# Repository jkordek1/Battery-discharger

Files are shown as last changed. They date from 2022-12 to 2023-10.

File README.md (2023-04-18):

# Battery discharger


[]()



## Why do you need this?

If you have a lot of 18650 Li-Ion battery cells that you won't be using any time soon you need to discharge them. In order for cells to stay healthy and remain their capacirty, they need to be stored at 50% of capacity (3.7 - 3.8V).
This device discharges the batteries to the storage level voltage.

## What is it?

 Automated battery discharger for Li-Po and Li-Ion batteries powered by ATmega328p microcontroller.
 Used for safely discharging 4 single-cell 18650 batteries to a storage level voltage (3.7V).
 No need for external power, the circuit is powered from cell #1.
 
 First push button switches between voltage and current monitoring.
 Second push button is used for manual voltage level measurement and for deactivating the buzzer.
 
 The code is written in Arduino and is available to download.
 
 The device is functional but could be improved.
 
 ## Features
 
 - 1.3" OLED screen
 - 2 push buttons used as controls
 - Buzzer for audio queues
 - ISP programming port
 - 4x 18650 battery discharging at the same time
 
 ## TO-DO
 - implement voltage level selection via push buttons 

## Images
<p align="center">
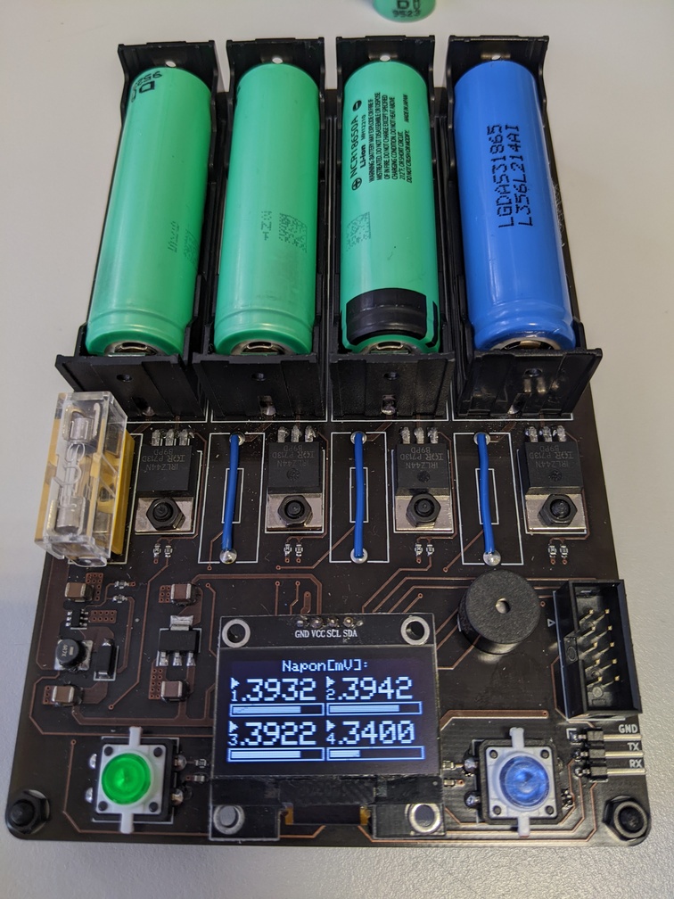
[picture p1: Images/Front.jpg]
  
</p>

## Project folder structure
    .
    ├── ...
    ├── 3D models               # 3D models of added components
    ├── ArduinoCode             # .ino file for Arduino
    ├── Images                  # Images of the project
    ├── KiCAD_Files             # Main folder
    │   ├── bom                 # ibom folder for assembly
    │   ├── gerber              # gerber output folder
    │   └── jlcpcb              # gerber and assembly folder - addon
    └── ...

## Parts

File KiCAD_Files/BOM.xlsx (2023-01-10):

Component | Description | Part | Value | Footprint | Quantity Per PCB | Datasheet | Basic/Extended | JLCPCB Part # | U labosu?
1 | Single-cell battery | Battery_Cell | 4V2 - 18650 | 18650-holder | 4 | ~
2 | Unpolarized capacitor, small symbol | C_Small | 100n | C_0603_1608Metric | 5 | ~ | Basic | C49678 | Da
3 | Unpolarized capacitor, small symbol | C_Small | 10u | C_1210_3225Metric | 2 | ~ |  | C337451 | ne
4 | Unpolarized capacitor, small symbol | C_Small | 22u / 16V | C_1210_3225Metric | 2 | ~ |  | C337451 | ne
5 | Schottky diode, small symbol | D_Schottky_Small | SS12 | D_SMA | 1 | ~ |  | C2985002 | ne
6 | Fuse | Fuse | 2A | 696108003002 | 4 | ~
7 | Generic connector, single row, 01x04, script generated (kicad-library-utils/schlib/autogen/connector/) | Conn_01x04 | OLED | OLED | 1 | ~
8 | Generic connector, single row, 01x03, script generated (kicad-library-utils/schlib/autogen/connector/) | Conn_01x03 | UART | PinHeader_1x03_P2.54mm_Horizontal | 1 | ~
9 | Generic connector, double row, 02x05, odd/even pin numbering scheme (row 1 odd numbers, row 2 even numbers), script generated (kicad-library-utils/schlib/autogen/connector/) | Conn_02x05_Odd_Even | USBasp | IDC-Header_2x05_P2.54mm_Vertical | 1 | ~
10 | Inductor, small symbol | L_Small | 10u | L_1206_3216Metric | 1 | ~ | Extended | C279941 | Ne
11 | Inductor, small symbol | L_Small | 4R7 | Inductor_4mm(5x5mm pads) | 1 | ~ |  |  | da
12 | Speaker | Speaker | Buzzer | Buzzer_TDK_PS1240P02BT_D12.2mm_H6.5mm | 1 | ~
13 | 47A Id, 55V Vds, 22mOhm Rds Single N-Channel HEXFET Power MOSFET, TO-220AB | IRLZ44N | IRLZ44N | TO-220-3_Horizontal_TabDown | 4 | http://www.irf.com/product-info/datasheets/data/irlz44n.pdf
14 | Resistor | R | 100 | R_0603_1608Metric | 6 | ~
15 | Resistor, small symbol | R_Small | 10k | R_0603_1608Metric | 5 | ~ | Basic | C17414 | Da
16 | Resistor, small symbol | R_Small | 13k3 | R_0603_1608Metric | 1 | ~ |  | C185373 | ne
17 | Resistor, small symbol | R_Small | 100k | R_0603_1608Metric | 1 | ~ |  |  | da
18 | Resistor | R | 3R3, 10W | PRW0AWJW33JB00 | 4 | ~
19 | Push button switch, generic, two pins | SW_Push | SW_Push | Omron_B3F-12x12mm | 2 | ~
20 | 1A Low Dropout regulator, positive, 3.3V fixed output, SOT-223 | AMS1117-3.3 | AMS1117-3.3 | SOT-223-3_TabPin2 | 1 | http://www.advanced-monolithic.com/pdf/ds1117.pdf
21 | 20MHz, 32kB Flash, 2kB SRAM, 1kB EEPROM, TQFP-32 | ATmega328-A | ATmega328-A | TQFP-32_7x7mm_P0.8mm | 1 | http://ww1.microchip.com/downloads/en/DeviceDoc/ATmega328_P%20AVR%20MCU%20with%20picoPower%20Technology%20Data%20Sheet%2040001984A.pdf
22 | High Efficiency 1.2MHz 2A Step Up Converter, 2-24V Vin, 28V Vout, 4A current limit, 1.2MHz, SOT23-6 | MT3608 | MT3608 | SOT-23-6 | 1 | https://www.olimex.com/Products/Breadboarding/BB-PWR-3608/resources/MT3608.pdf |  | C2932326 | da
23 | Three pin ceramic resonator, small symbol | Resonator_Small | 16MHz | CSTCE16M0V53-R0 | 1 | ~ | Extended | C32180 | Da

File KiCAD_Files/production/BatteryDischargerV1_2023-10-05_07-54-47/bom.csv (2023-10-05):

Designator | Footprint | Quantity | Value | LCSC Part #
BT1, BT2, BT3, BT4 | 18650-holder | 4 | 4V2 - 18650
C1, C2, C3 | 0603 | 3 | 100n | C49678
C5, C6 | 1210 | 2 | 22u / 16V | C337451
C7, C8 | 1210 | 2 | 10u | C337451
CD1, CD2 | 0603 | 2 | 100n
D1 | D_SMA | 1 | SS12 | C2985002
F1, F2, F3, F4 | 696108003002 | 4 | 2A
H1, H2, H3, H4 | MountingHole_3.2mm_M3_Pad_Via | 4 | MountingHole
J1 | IDC-Header_2x05_P2.54mm_Vertical | 1 | USBasp
J2 | OLED | 1 | OLED
J3 | PinHeader_1x03_P2.54mm_Horizontal | 1 | UART
L1 | 1206 | 1 | 10u | C279941
L2 | Inductor_4mm(5x5mm pads) | 1 | 4R7
LS1 | Buzzer_TDK_PS1240P02BT_D12.2mm_H6.5mm | 1 | Buzzer
Q1, Q2, Q3, Q4 | TO-220-3_Horizontal_TabDown | 4 | IRLZ44N
R10 | 0603 | 1 | 13k3 | C185373
R11, R12, R17, R18 | PRW0AWJW33JB00 | 4 | 3R3, 10W
R13, R14, R19, R20, R7, R8 | 0603 | 6 | 100
R15, R16, R21, R22 | 0603 | 4 | 10k
R4 | 0603 | 1 | 10k | C17414
R9 | 0603 | 1 | 100k
SW1, SW2 | Omron_B3F-12x12mm | 2 | SW_Push
U1 | TQFP-32_7x7mm_P0.8mm | 1 | ATmega328-A
U2 | SOT-223-3_TabPin2 | 1 | AMS1117-3.3
U3 | SOT-23-6 | 1 | MT3608 | C2932326
Y1 | CSTCE16M0V53-R0 | 1 | 16MHz | C32180

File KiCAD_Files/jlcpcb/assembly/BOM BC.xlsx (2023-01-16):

Designator | Designation | Package | Quantity | link
R4,R15,R16,R22,R21 | 10k | 0603 SMD | 5
C2,CD1,CD2,C1,C3 | 100n | 0603 SMD | 5
SW2,SW1 | SW_Push | Omron_B3F-4000-12x12mm | 2 | digikey (https://www.digikey.com/en/products/detail/omron-electronics-inc-emc-div/B3F-4000/63961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)
C7,C8 | 10u | 1210 SMD | 2
F2,F3,F1,F4 | 2A | 696108003002 | 4 | digikey (https://www.digikey.com/en/products/detail/w%C3%BCrth-elektronik/696108003002/7244560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)
R9 | 100k | 0603 SMD | 1
LS1 | Buzzer | Buzzer_TDK_PS1240P02BT_D12.2mm_H6.5mm | 1 | digikey (https://www.digikey.com/en/products/detail/tdk-corporation/PS1240P02BT/935924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)
Q2,Q3,Q1,Q4 | IRLZ44N | TO-220 | 4
R10 | 13k3 | 0603 SMD | 1
R7,R19,R8,R13,R14,R20 | 100R | 0603 SMD | 6
J1 | USBasp | IDC-Header_2x05_P2.54mm_Vertical | 1
C6,C5 | 22u / 16V | C_1210_3225Metric | 2
U3 | MT3608 | SOT-23-6 | 1
U2 | AMS1117-3.3 | SOT-223-3_TabPin2 | 1
D1 | SS12 | D_SMA | 1 | mouser (https://hr.mouser.com/ProductDetail/onsemi-Fairchild/SS12?qs=mVVXn4M53U9WoaEpU1CO0A%3D%3D)
L1 | 10u | 1206 SMD | 1
R18,R17,R12,R11 | 3R3, 10W | PRW0AWJW33JB00 | 4 | tme (https://www.tme.eu/en/details/ax10w-3r3/power-resistors/royal-ohm/prw0awjw33jb00/)

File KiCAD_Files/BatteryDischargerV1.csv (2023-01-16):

Source: | C:\Users\Josip\Documents\GitHub\Battery-discharger\KiCAD Files\BatteryDischargerV1.kicad_sch
Date: | 16.1.2023. 12:32:26
Tool: | Eeschema (6.0.10)
Generator: | C:\Program Files\KiCad\6.0\bin\scripting\plugins/bom_csv_grouped_by_value_with_fp.py
Component Count: | 55
Ref | Qnty | Value | Cmp name | Footprint | Description | Vendor
BT1, BT2, BT3, BT4, | 4 | 4V2 - 18650 | Battery_Cell | Footprint:18650-holder | Single-cell battery
C1, C2, C3, | 3 | 100n | C_Small | Capacitor_SMD:C_0603_1608Metric | Unpolarized capacitor, small symbol
C5, C6, | 2 | 22u / 16V | C_Small | Capacitor_SMD:C_1210_3225Metric | Unpolarized capacitor, small symbol
C7, C8, | 2 | 10u | C_Small | Capacitor_SMD:C_1210_3225Metric | Unpolarized capacitor, small symbol
CD1, CD2, | 2 | 100n | C | Capacitor_SMD:C_0603_1608Metric | Unpolarized capacitor
D1, | 1 | SS12 | D_Schottky_Small | Diode_SMD:D_SMA | Schottky diode, small symbol
F1, F2, F3, F4, | 4 | 2A | Fuse | Footprint:696108003002 | Fuse
H1, H2, H3, H4, | 4 | MountingHole | MountingHole_Pad | MountingHole:MountingHole_3.2mm_M3_Pad_Via | Mounting Hole with connection
J1, | 1 | USBasp | Conn_02x05_Odd_Even | Connector_IDC:IDC-Header_2x05_P2.54mm_Vertical | Generic connector, double row, 02x05, odd/even pin numbering scheme (row 1 odd numbers, row 2 even numbers), script generated (kicad-library-utils/schlib/autogen/connector/)
J2, | 1 | OLED | Conn_01x04 | Footprint:OLED | Generic connector, single row, 01x04, script generated (kicad-library-utils/schlib/autogen/connector/)
J3, | 1 | UART | Conn_01x03 | Connector_PinHeader_2.54mm:PinHeader_1x03_P2.54mm_Horizontal | Generic connector, single row, 01x03, script generated (kicad-library-utils/schlib/autogen/connector/)
L1, | 1 | 10u | L_Small | Inductor_SMD:L_1206_3216Metric | Inductor, small symbol
L2, | 1 | 4R7 | L_Small | Footprint:Inductor_4mm(5x5mm pads) | Inductor, small symbol
LS1, | 1 | Buzzer | Speaker | Buzzer_Beeper:Buzzer_TDK_PS1240P02BT_D12.2mm_H6.5mm | Speaker
Q1, Q2, Q3, Q4, | 4 | IRLZ44N | IRLZ44N | Package_TO_SOT_THT:TO-220-3_Horizontal_TabDown | 47A Id, 55V Vds, 22mOhm Rds Single N-Channel HEXFET Power MOSFET, TO-220AB
R4, R15, R16, R21, R22, | 5 | 10k | R_Small | Resistor_SMD:R_0603_1608Metric | Resistor, small symbol
R7, R8, R13, R14, R19, R20, | 6 | 100 | R_Small | Resistor_SMD:R_0603_1608Metric | Resistor, small symbol
R9, | 1 | 100k | R_Small | Resistor_SMD:R_0603_1608Metric | Resistor, small symbol
R10, | 1 | 13k3 | R_Small | Resistor_SMD:R_0603_1608Metric | Resistor, small symbol
R11, R12, R17, R18, | 4 | 3R3, 10W | R | Footprint:PRW0AWJW33JB00 | Resistor
SW1, SW2, | 2 | SW_Push | SW_Push | Footprint:Omron_B3F-12x12mm | Push button switch, generic, two pins
U1, | 1 | ATmega328-A | ATmega328-A | Package_QFP:TQFP-32_7x7mm_P0.8mm | 20MHz, 32kB Flash, 2kB SRAM, 1kB EEPROM, TQFP-32
U2, | 1 | AMS1117-3.3 | AMS1117-3.3 | Package_TO_SOT_SMD:SOT-223-3_TabPin2 | 1A Low Dropout regulator, positive, 3.3V fixed output, SOT-223
U3, | 1 | MT3608 | MT3608 | Package_TO_SOT_SMD:SOT-23-6 | High Efficiency 1.2MHz 2A Step Up Converter, 2-24V Vin, 28V Vout, 4A current limit, 1.2MHz, SOT23-6
Y1, | 1 | 16MHz | Resonator_Small | Footprint:CSTCE16M0V53-R0 | Three pin ceramic resonator, small symbol

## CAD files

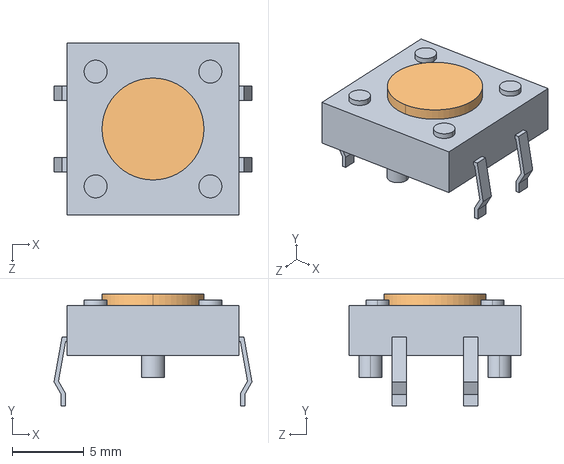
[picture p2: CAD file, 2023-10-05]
3D models/B3F_4005.step
13.8 x 7.80 x 12.0 mm
B3F_4005_BASE
B3F_4005_BUTTON

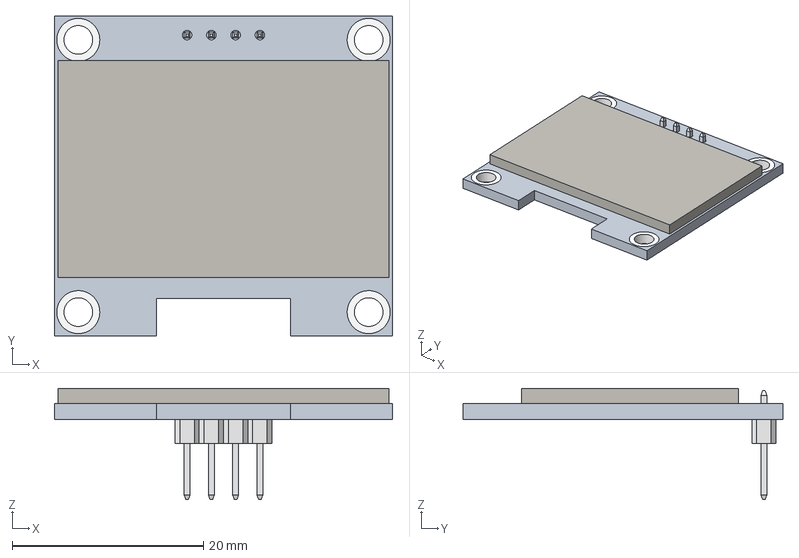
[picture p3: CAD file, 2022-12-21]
3D models/Geekcreit 1.3 Inch 4Pin.step
35.4 x 33.5 x 11.6 mm
2.54mm_pin_header x 4

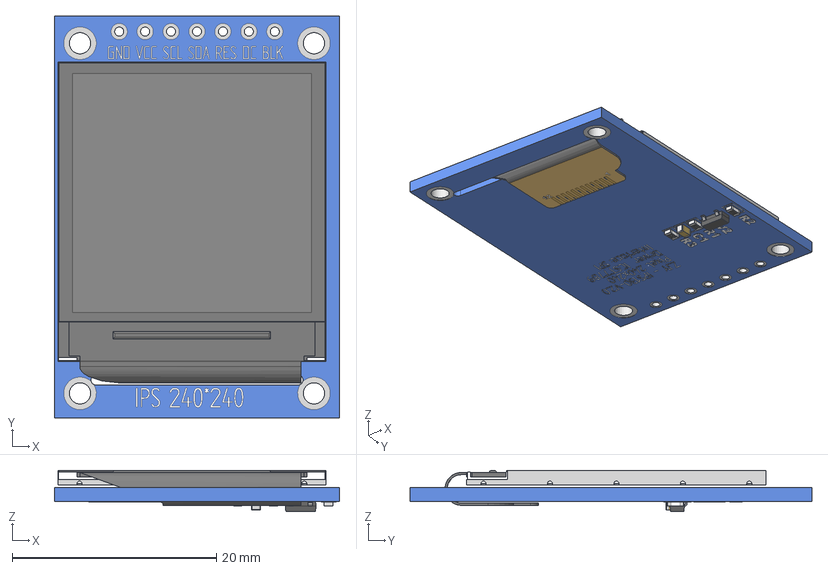
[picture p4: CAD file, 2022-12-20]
3D models/1.3 TFT IPS - Module.stp
27.9 x 39.4 x 4.06 mm
1.3 TFT IPS - Board
1.3 TFT IPS - Flush Reverse Mount
0603 Resistor x 3
0603 Capacitor
SOT-23

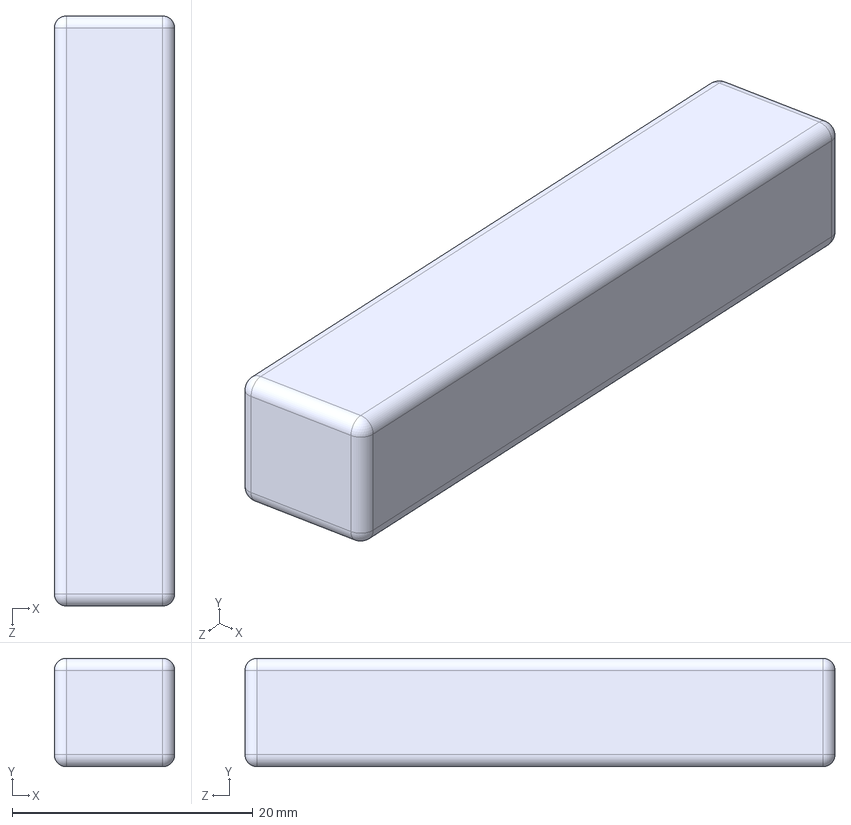
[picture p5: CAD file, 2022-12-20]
3D models/3R3-10W.STEP
10.0 x 9.00 x 49.0 mm

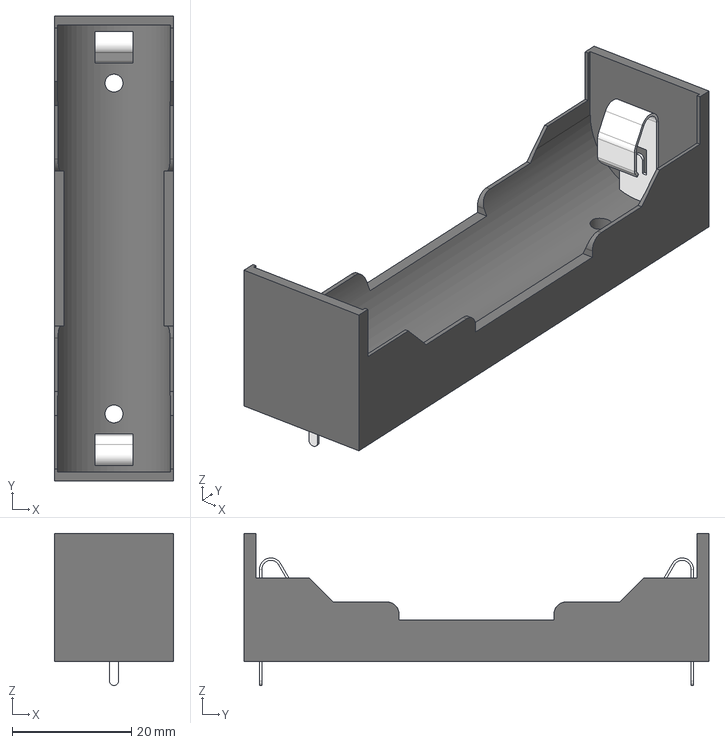
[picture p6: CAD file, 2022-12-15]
3D models/Hold_18650-1p.stp
20.0 x 78.0 x 25.5 mm

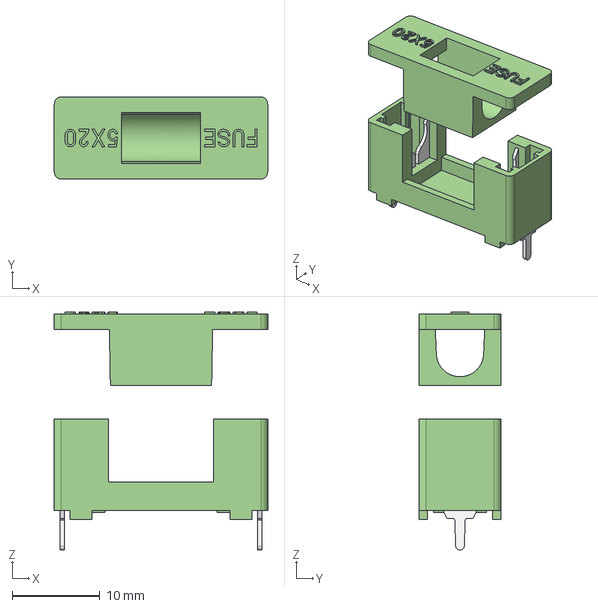
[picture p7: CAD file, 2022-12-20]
3D models/696108003002 (rev1).stp
24.4 x 9.40 x 27.2 mm

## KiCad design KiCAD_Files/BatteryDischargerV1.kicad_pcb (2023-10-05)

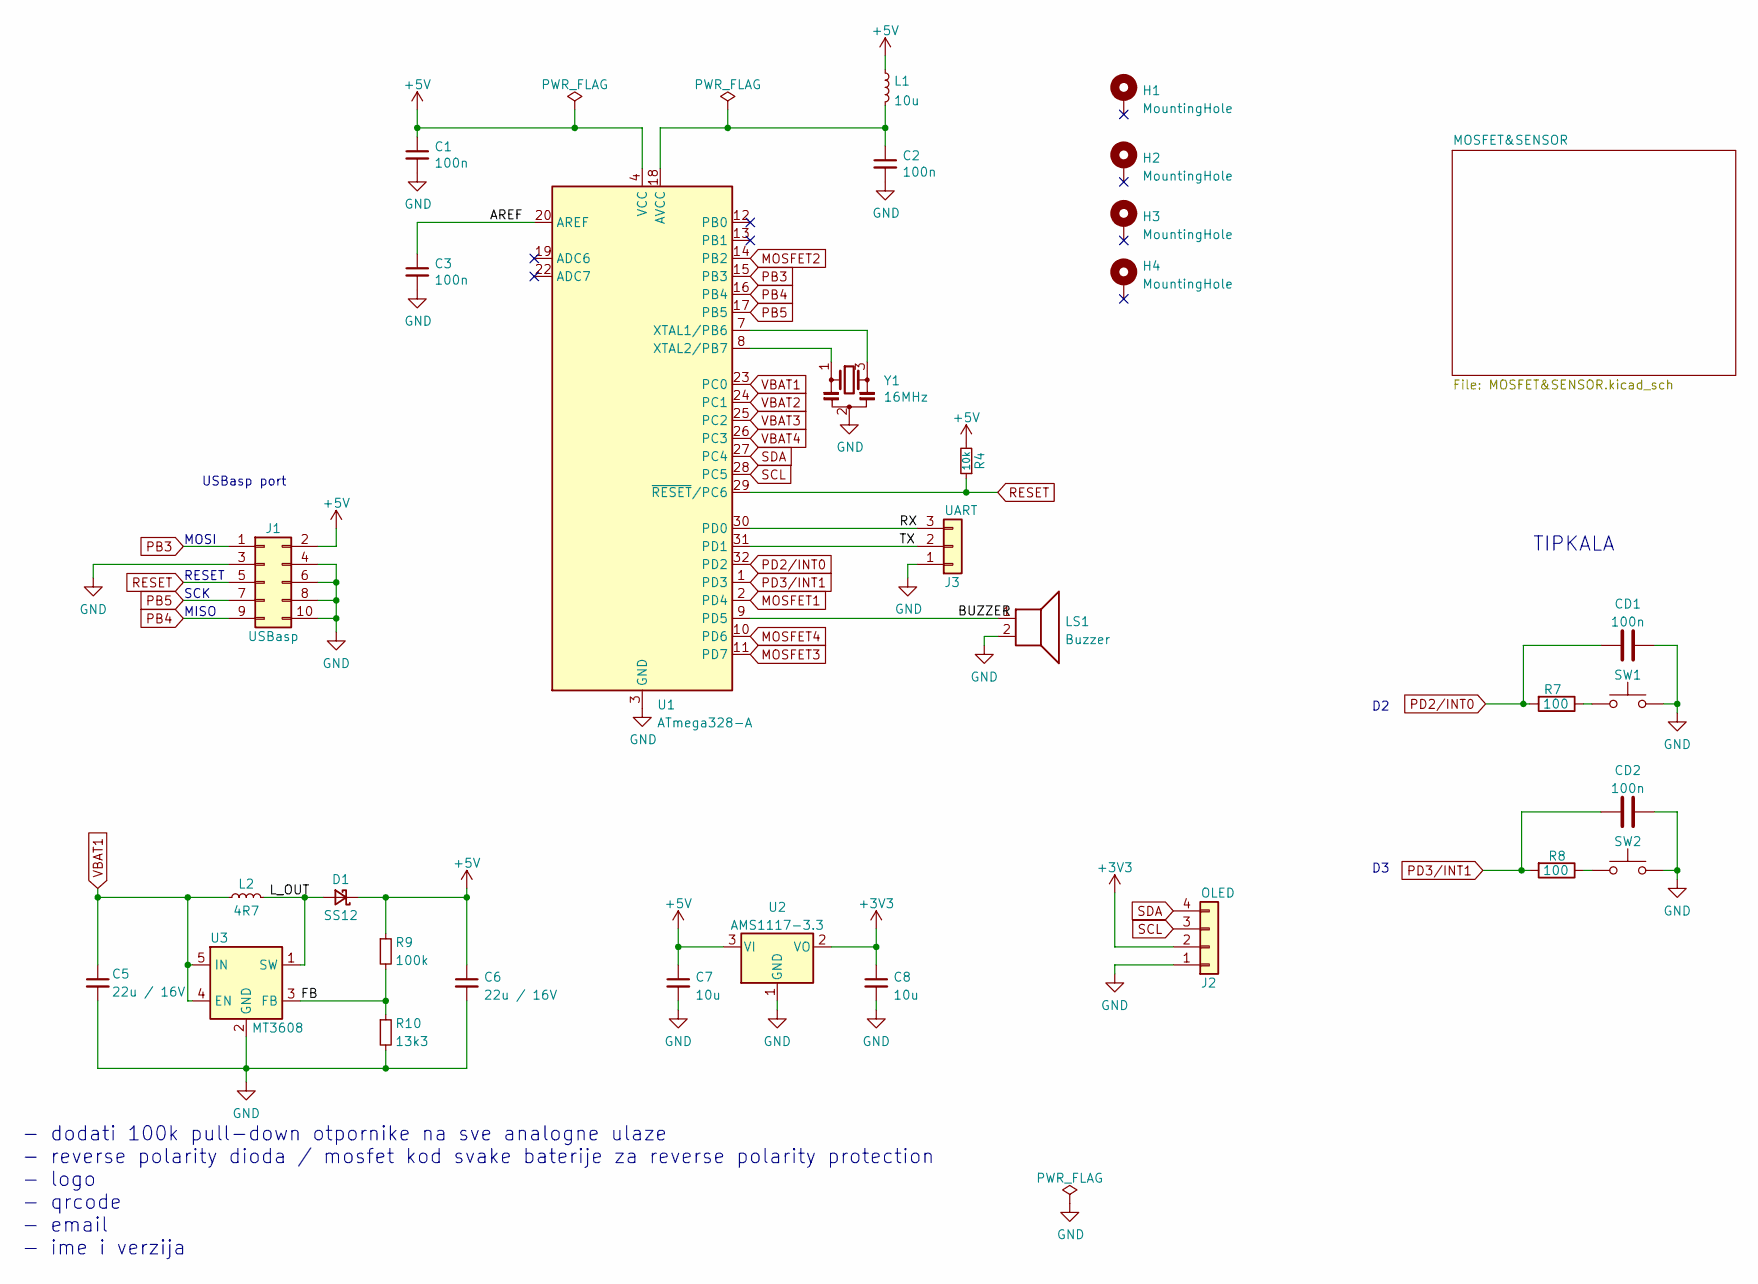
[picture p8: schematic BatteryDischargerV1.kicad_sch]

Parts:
C1, C2, C3: 100n; C_0603_1608Metric; JLCPCB Part # C49678
C5, C6: 22u / 16V; C_1210_3225Metric; JLCPCB Part # C337451
C7, C8: 10u; C_1210_3225Metric; JLCPCB Part # C337451
CD1, CD2: 100n; C_0603_1608Metric
D1: SS12; D_SMA; JLCPCB Part # C2985002
H1, H2, H3, H4: MountingHole; MountingHole_3.2mm_M3_Pad_Via
J1: USBasp; IDC-Header_2x05_P2.54mm_Vertical
J2: OLED
J3: UART; PinHeader_1x03_P2.54mm_Horizontal
L1: 10u; L_1206_3216Metric; JLCPCB Part # C279941
L2: 4R7; Inductor_4mm(5x5mm pads)
LS1: Buzzer; Buzzer_TDK_PS1240P02BT_D12.2mm_H6.5mm
R4: 10k; R_0603_1608Metric; JLCPCB Part # C17414
R7, R8: 100; R_0603_1608Metric
R9: 100k; R_0603_1608Metric
R10: 13k3; R_0603_1608Metric; JLCPCB Part # C185373
SW1, SW2: SW_Push; Omron_B3F-12x12mm
U1: ATmega328-A; TQFP-32_7x7mm_P0.8mm
U2: AMS1117-3.3; SOT-223-3_TabPin2
U3: MT3608; SOT-23-6; JLCPCB Part # C2932326
Y1: 16MHz; CSTCE16M0V53-R0; JLCPCB Part # C32180

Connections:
+3V3: C8.1, J2.2, U2.2 (VO)
+5V: C1.1, C6.1, C7.1, D1.1 (K), J1.2, L1.1, R4.2, R9.1, U1.4 (VCC), U1.6 (VCC), U2.3 (VI)
/AREF: C3.1, U1.20 (AREF)
/BUZZER: LS1.1, U1.9 (PD5)
/FB: R9.2, R10.1, U3.3 (FB)
/L_OUT: D1.2 (A), L2.2, U3.1 (SW)
/RX: J3.3, U1.30 (PD0)
/TX: J3.2, U1.31 (PD1)
GND: C1.2, C2.2, C3.2, C5.2, C6.2, C7.2, C8.2, CD1.2, CD2.2, J1.3, J1.4, J1.6, J1.8, J1.10, J2.1, J3.1, LS1.2, R10.2, SW1.2, SW2.2, U1.3 (GND), U1.5 (GND), U1.21 (GND), U2.1 (GND), U3.2 (GND), Y1.2; also elsewhere on the board
MOSFET1: U1.2 (PD4); also elsewhere on the board
MOSFET2: U1.14 (PB2); also elsewhere on the board
MOSFET3: U1.11 (PD7); also elsewhere on the board
MOSFET4: U1.10 (PD6); also elsewhere on the board
unnamed: C2.1, L1.2, U1.18 (AVCC)
unnamed: R7.1, SW1.1
unnamed: R8.1, SW2.1
unnamed: U1.7 (XTAL1/PB6), Y1.3
unnamed: U1.8 (XTAL2/PB7), Y1.1
PB3: J1.1, U1.15 (PB3)
PB4: J1.9, U1.16 (PB4)
PB5: J1.7, U1.17 (PB5)
PD2/INT0: CD1.1, R7.2, U1.32 (PD2)
PD3/INT1: CD2.1, R8.2, U1.1 (PD3)
RESET: J1.5, R4.1, U1.29 (~RESET/PC6)
SCL: J2.3, U1.28 (PC5)
SDA: J2.4, U1.27 (PC4)
VBAT1: C5.1, L2.1, U1.23 (PC0), U3.4 (EN), U3.5 (IN); also elsewhere on the board
VBAT2: U1.24 (PC1); also elsewhere on the board
VBAT3: U1.25 (PC2); also elsewhere on the board
VBAT4: U1.26 (PC3); also elsewhere on the board

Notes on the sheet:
USBasp port
MISO
RESET
- dodati 100k pull-down otpornike na sve analogne ulaze - reverse polarity dioda / mosfet kod svake baterije za reverse polarity protection - logo - qrcode - email - ime i verzija
SCK
TIPKALA
MOSI

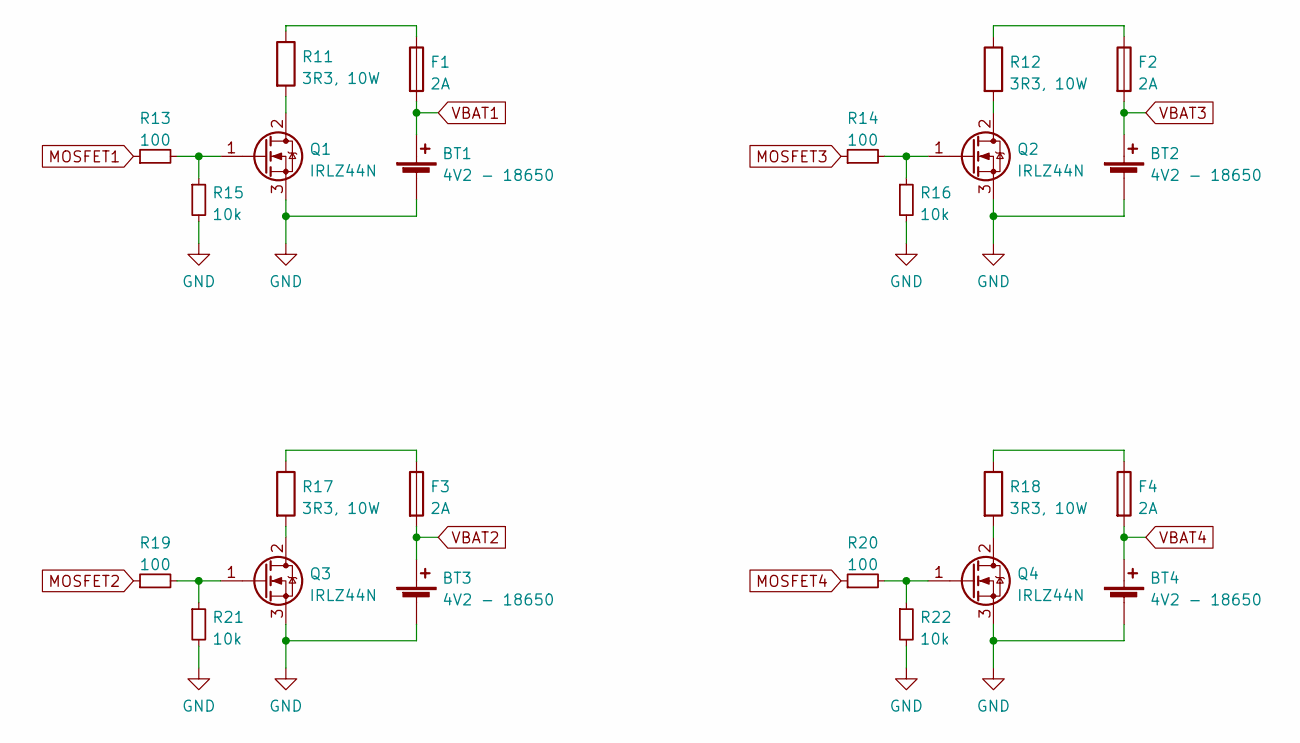
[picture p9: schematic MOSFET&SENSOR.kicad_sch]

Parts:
BT1, BT2, BT3, BT4: 4V2 - 18650; 18650-holder
F1, F2, F3, F4: 2A; 696108003002
Q1, Q2, Q3, Q4: IRLZ44N; TO-220-3_Horizontal_TabDown
R11, R12, R17, R18: 3R3, 10W; PRW0AWJW33JB00
R13, R14, R19, R20: 100; R_0603_1608Metric
R15, R16, R21, R22: 10k; R_0603_1608Metric

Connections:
GND: BT1.2 (-), BT2.2 (-), BT3.2 (-), BT4.2 (-), Q1.3 (S), Q2.3 (S), Q3.3 (S), Q4.3 (S), R15.2, R16.2, R21.2, R22.2; also elsewhere on the board
MOSFET1: R13.1; also elsewhere on the board
MOSFET2: R19.1; also elsewhere on the board
MOSFET3: R14.1; also elsewhere on the board
MOSFET4: R20.1; also elsewhere on the board
unnamed: F1.1, R11.1
unnamed: F2.1, R12.1
unnamed: F3.1, R17.1
unnamed: F4.1, R18.1
unnamed: Q1.1 (G), R13.2, R15.1
unnamed: Q1.2 (D), R11.2
unnamed: Q2.1 (G), R14.2, R16.1
unnamed: Q2.2 (D), R12.2
unnamed: Q3.1 (G), R19.2, R21.1
unnamed: Q3.2 (D), R17.2
unnamed: Q4.1 (G), R20.2, R22.1
unnamed: Q4.2 (D), R18.2
VBAT1: BT1.1 (+), F1.2; also elsewhere on the board
VBAT2: BT3.1 (+), F3.2; also elsewhere on the board
VBAT3: BT2.1 (+), F2.2; also elsewhere on the board
VBAT4: BT4.1 (+), F4.2; also elsewhere on the board

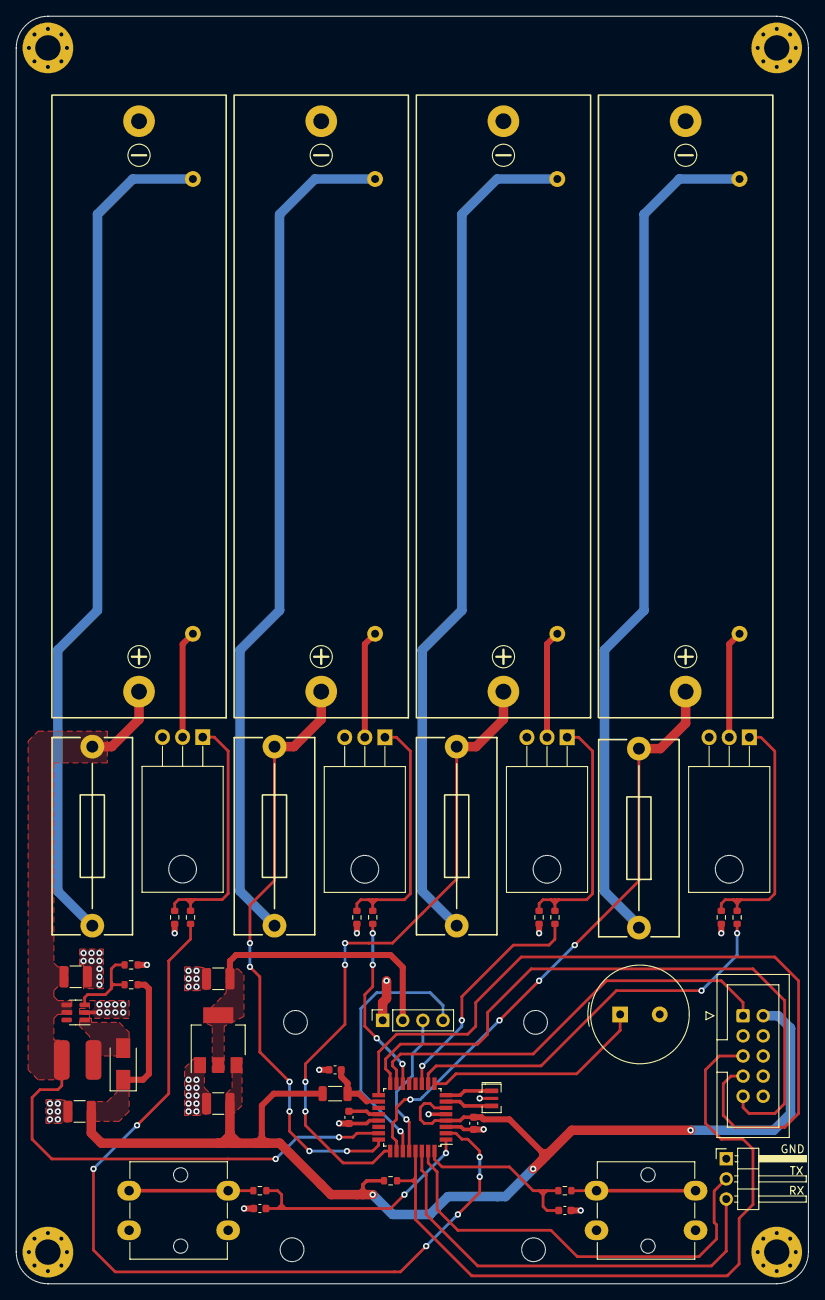
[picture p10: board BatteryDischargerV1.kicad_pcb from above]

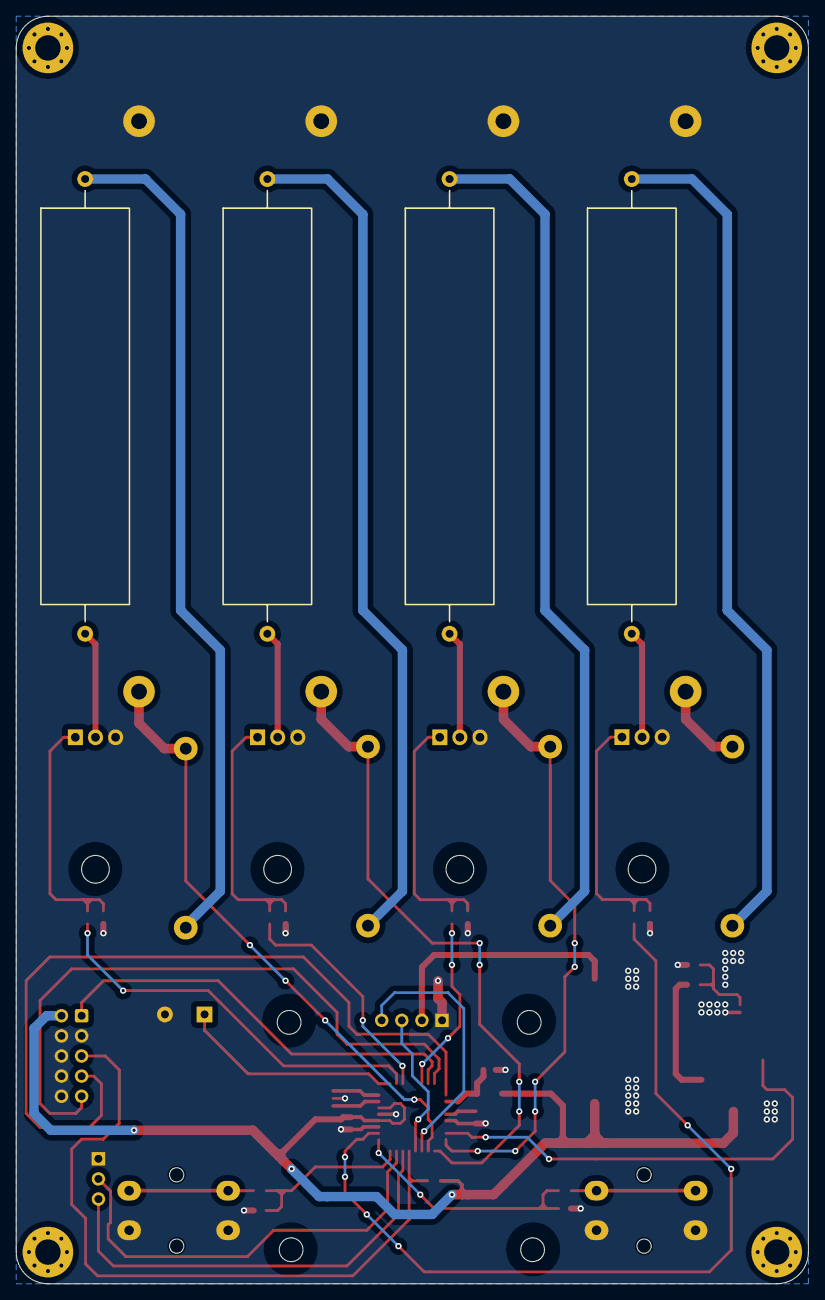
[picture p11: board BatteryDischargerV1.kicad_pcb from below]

Board: 2 copper layers, 100.0 x 160.0 mm, 55 parts (5 on the bottom side), 42 nets.

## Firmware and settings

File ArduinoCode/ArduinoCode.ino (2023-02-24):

#include <Wire.h>
#include <Adafruit_GFX.h>
#include <Adafruit_SH110X.h>

#define buzzer 5

#define M1 4          //MOSFET1
#define M2 10         //MOSFET2
#define M3 7          //MOSFET3
#define M4 6          //MOSFET4
#define buttonPin1 3
#define buttonPin2 2

#define BAT1AI  0        //BAT1AI analog input
#define BAT2AI  1        //BAT2AI analog input
#define BAT3AI  2        //BAT3AI analog input
#define BAT4AI  3        //BAT4AI analog input 

#define voltage 3700

bool BAT1DC = false;
bool BAT2DC = false;
bool BAT3DC = false;
bool BAT4DC = false;

bool buzzing = false;
bool buzzing2 = false;

uint16_t struja = 0;
uint8_t screen = 1;

uint16_t bat1Voltage = 0;
uint16_t bat2Voltage = 0;
uint16_t bat3Voltage = 0;
uint16_t bat4Voltage = 0;

uint8_t brojacIspis = 1;
uint16_t brojacMjerenje = 1;

uint32_t loopInterval = 50;
uint32_t previousMillis = 0;
uint32_t currentMillis = 0;
uint8_t buzzerBrojac = 0;

bool mjerenje = true;

#define SCREEN_WIDTH 128 // OLED display width, in pixels
#define SCREEN_HEIGHT 64 // OLED display height, in pixels
#define i2c_Address 0x3c //initialize with the I2C addr 0x3C Typically eBay OLED's
#define OLED_RESET -1   //   QT-PY / XIAO
Adafruit_SH1106G display = Adafruit_SH1106G(SCREEN_WIDTH, SCREEN_HEIGHT, &Wire, OLED_RESET);


void setup() {

  Serial.begin(9600);

  pinMode(buzzer, OUTPUT);
  pinMode(M1, OUTPUT);
  pinMode(M2, OUTPUT);
  pinMode(M3, OUTPUT);
  pinMode(M4, OUTPUT);

  pinMode(buttonPin1, INPUT_PULLUP);
  pinMode(buttonPin2, INPUT_PULLUP);

  digitalWrite(M1, BAT1DC);
  digitalWrite(M2, BAT2DC);
  digitalWrite(M3, BAT3DC);
  digitalWrite(M4, BAT4DC);

  attachInterrupt(digitalPinToInterrupt(buttonPin1), tipkalo1, FALLING);
  attachInterrupt(digitalPinToInterrupt(buttonPin2), tipkalo2, FALLING);

  if (!display.begin(i2c_Address, true)) { // Address 0x3D for 128x64
    Serial.println(F("SSD1306 allocation failed"));
    for (;;);
  }

  display.cp437(true);
  display.clearDisplay();
  display.setTextColor(SH110X_WHITE);
  display.display();
}

void loop() {

  currentMillis = millis();

  if ((currentMillis - previousMillis) >= loopInterval) { // 50 ms

    brojacIspis++;
    brojacMjerenje++;
    buzzerBrojac++;

    if (buzzerBrojac >= 10 && buzzing) {
      if (buzzing2) tone(buzzer, 500);
      else noTone(buzzer);
      buzzing2 = !buzzing2;
      buzzerBrojac = 0;
    }

    if (brojacIspis >= 7) { //300 ms

      bat1Voltage = getVoltage(BAT1AI);
      bat2Voltage = getVoltage(BAT2AI);
      bat3Voltage = getVoltage(BAT3AI);
      bat4Voltage = getVoltage(BAT4AI);

      ispis(screen);
      brojacIspis = 1;
    }
    if (brojacMjerenje >= 1200) { //
      mjerenje = true;

      digitalWrite(M1, false);
      digitalWrite(M2, false);
      digitalWrite(M3, false);
      digitalWrite(M4, false);

      brojacMjerenje = 1;
    }
    if (mjerenje == true && brojacMjerenje > 200) {
      mjerenje = false;
      if (getVoltage(BAT1AI) > voltage) BAT1DC = true;
      else BAT1DC = false;
      if (getVoltage(BAT2AI) > voltage) BAT2DC = true;
      else BAT2DC = false;
      if (getVoltage(BAT3AI) > voltage) BAT3DC = true;
      else BAT3DC = false;
      if (getVoltage(BAT4AI) > voltage) BAT4DC = true;
      else BAT4DC = false;

      if (((getVoltage(BAT1AI) < voltage) && (getVoltage(BAT1AI) > 1000)) || ((getVoltage(BAT2AI) < voltage) && (getVoltage(BAT2AI) > 1000)) || ((getVoltage(BAT3AI) < voltage) && (getVoltage(BAT3AI) > 1000)) || ((getVoltage(BAT4AI) < voltage)  && (getVoltage(BAT4AI) > 1000))) {
        buzzing = true;
      }

      digitalWrite(M1, BAT1DC);
      digitalWrite(M2, BAT2DC);
      digitalWrite(M3, BAT3DC);
      digitalWrite(M4, BAT4DC);
    }

    previousMillis = currentMillis;
  }

  //  tone(buzzer, 500); // Send 1KHz sound signal...
  //  delay(100);        // ...for 1 sec
  //  noTone(buzzer);     // Stop sound...
  //  delay(100);        // ...for 1sec


}

int getVoltage (int pin) {
  int napon = 0;
  for (int i = 0; i < 30; i++) {
    napon += analogRead(pin);
  }
  napon = napon / 30.0;
  napon = napon * 5086.0 / 1023.0; //5V regulator napon daje cca 5.086V
  return napon;
}

void tipkalo1() {

  screen++;

  if (screen == 3) screen = 1;
}

void tipkalo2() {

  BAT1DC = false;
  BAT2DC = false;
  BAT3DC = false;
  BAT4DC = false;

  digitalWrite(M1, BAT1DC);
  digitalWrite(M2, BAT2DC);
  digitalWrite(M3, BAT3DC);
  digitalWrite(M4, BAT4DC);

  mjerenje = true;
  brojacMjerenje = 0;

  buzzing = false;
  buzzerBrojac = 0;
  noTone(buzzer);

}

void ispis(int screen) {

  display.clearDisplay();

  if (screen == 1) {
    screen1();
  }
  else if (screen == 2) {
    screen2();
  }

  display.display();
}

void screen1() {

  display.setCursor(35, 0);
  display.setTextSize(1);
  display.print("Napon[mV]:");

  //1
  display.drawRect(0, 28, 63, 8, SH110X_WHITE);

  //2
  display.drawRect(65, 28, 63, 8, SH110X_WHITE);

  //3
  display.drawRect(0, 56, 63, 8, SH110X_WHITE);

  //4
  display.drawRect(65, 56, 63, 8, SH110X_WHITE);

  display.setCursor(0, 11);
  display.setTextSize(1);
  if (BAT1DC) display.write(0x10);

  display.setCursor(0, 19);
  display.print("1.");
  display.setCursor(11, 12);
  display.setTextSize(2);
  if (bat1Voltage < 500) bat1Voltage = 0;
  display.print(bat1Voltage);
  float postotak = (49.17 * bat1Voltage / 1000.0) - 147.5;
  if (postotak > 59) postotak = 59;
  else if (postotak < 0) postotak = 0;
  display.fillRect(2, 30, postotak, 4, SH110X_WHITE); // pocX, pocY, velX, velY //velX min 0, max 59

  display.setCursor(65, 11);
  display.setTextSize(1);
  if (BAT2DC) display.write(0x10);

  display.setCursor(65, 19);
  display.print("2.");
  display.setCursor(76, 12);
  display.setTextSize(2);
  display.print(bat2Voltage);
  postotak = (49.17 * bat2Voltage / 1000.0) - 147.5;
  if (postotak > 59) postotak = 59;
  else if (postotak < 0) postotak = 0;
  display.fillRect(67, 30, postotak, 4, SH110X_WHITE); // pocX, pocY, velX, velY //velX min 0, max 59

  display.setCursor(0, 39);
  display.setTextSize(1);
  if (BAT3DC) display.write(0x10);

  display.setCursor(0, 47);
  display.print("3.");
  display.setCursor(11, 40);
  display.setTextSize(2);
  display.print(bat3Voltage);
  postotak = (49.17 * bat3Voltage / 1000.0) - 147.5;
  if (postotak > 59) postotak = 59;
  else if (postotak < 0) postotak = 0;
  display.fillRect(2, 58, postotak, 4, SH110X_WHITE); // pocX, pocY, velX, velY //velX min 0, max 59

  display.setCursor(65, 39);
  display.setTextSize(1);
  if (BAT4DC) display.write(0x10);

  display.setCursor(65, 47);
  display.print("4.");
  display.setCursor(76, 40);
  display.setTextSize(2);
  display.print(bat4Voltage);
  postotak = (49.17 * bat4Voltage / 1000.0) - 147.5;
  if (postotak > 59) postotak = 59;
  else if (postotak < 0) postotak = 0;
  display.fillRect(67, 58, postotak, 4, SH110X_WHITE); // pocX, pocY, velX, velY //velX min 0, max 59

}

void screen2() {

  display.setCursor(35, 0);
  display.setTextSize(1);
  display.print("Struja[mA]:");

  //1
  display.drawRect(0, 28, 63, 8, SH110X_WHITE);

  //2
  display.drawRect(65, 28, 63, 8, SH110X_WHITE);

  //3
  display.drawRect(0, 56, 63, 8, SH110X_WHITE);

  //4
  display.drawRect(65, 56, 63, 8, SH110X_WHITE);

  display.setCursor(0, 11);
  display.setTextSize(1);
  if (BAT1DC) display.write(0x10);

  display.setCursor(0, 19);
  display.print("1.");
  display.setCursor(11, 12);
  display.setTextSize(2);
  if (BAT1DC) struja = bat1Voltage / 3.3;
  else struja = 0;
  display.print(struja);
  float postotak = (49.17 * bat1Voltage / 1000.0) - 147.5;
  if (postotak > 59) postotak = 59;
  else if (postotak < 0) postotak = 0;
  if (BAT1DC) display.fillRect(2, 30, postotak, 4, SH110X_WHITE); // pocX, pocY, velX, velY //velX min 0, max 59

  display.setCursor(65, 11);
  display.setTextSize(1);
  if (BAT2DC) display.write(0x10);

  display.setCursor(65, 19);
  display.print("2.");
  display.setCursor(76, 12);
  display.setTextSize(2);
  if (BAT2DC) struja = bat2Voltage / 3.3;
  else struja = 0;
  display.print(struja);
  postotak = (49.17 * bat2Voltage / 1000.0) - 147.5;
  if (postotak > 59) postotak = 59;
  else if (postotak < 0) postotak = 0;
  if (BAT2DC) display.fillRect(67, 30, postotak, 4, SH110X_WHITE); // pocX, pocY, velX, velY //velX min 0, max 59

  display.setCursor(0, 39);
  display.setTextSize(1);
  if (BAT3DC) display.write(0x10);

  display.setCursor(0, 47);
  display.print("3.");
  display.setCursor(11, 40);
  display.setTextSize(2);
  if (BAT3DC) struja = bat3Voltage / 3.3;
  else struja = 0;
  display.print(struja);
  postotak = (49.17 * bat3Voltage / 1000.0) - 147.5;
  if (postotak > 59) postotak = 59;
  else if (postotak < 0) postotak = 0;
  if (BAT3DC) display.fillRect(2, 58, postotak, 4, SH110X_WHITE); // pocX, pocY, velX, velY //velX min 0, max 59

  display.setCursor(65, 39);
  display.setTextSize(1);
  if (BAT4DC) display.write(0x10);

  display.setCursor(65, 47);
  display.print("4.");
  display.setCursor(76, 40);
  display.setTextSize(2);
  if (BAT4DC) struja = bat4Voltage / 3.3;
  else struja = 0;
  display.print(struja);
  postotak = (49.17 * bat4Voltage / 1000.0) - 147.5;
  if (postotak > 59) postotak = 59;
  else if (postotak < 0) postotak = 0;
  if (BAT4DC) display.fillRect(67, 58, postotak, 4, SH110X_WHITE); // pocX, pocY, velX, velY //velX min 0, max 59

}
